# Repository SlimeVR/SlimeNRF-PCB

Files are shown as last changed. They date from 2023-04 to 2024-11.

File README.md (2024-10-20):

## notes

You need a segger jlink programmer to use this, USB dfu does not come with the initial bootloader of isp, and nrf52832 has no USB connectivity. nRF52840-dk development kit can be used, and also can double as a dongle for the trackers.

# slimenrf r3

Revision 3

E73-2G4M08S1C (nrf52840), icm42688 or compatible, mmc5983ma

https://oshwlab.com/sctanf/slimenrf3

# slimenrfaux2

Revision 2

isp1507-ax (nrf52832), icm42688 or compatible, mmc5983ma

* Uses nrf52832, no USB, SWD pins on dock connector instead
* No 0201 parts
* Removed onboard charger
* LED is brighter (sink instead of source)

pcb|3d
--|--
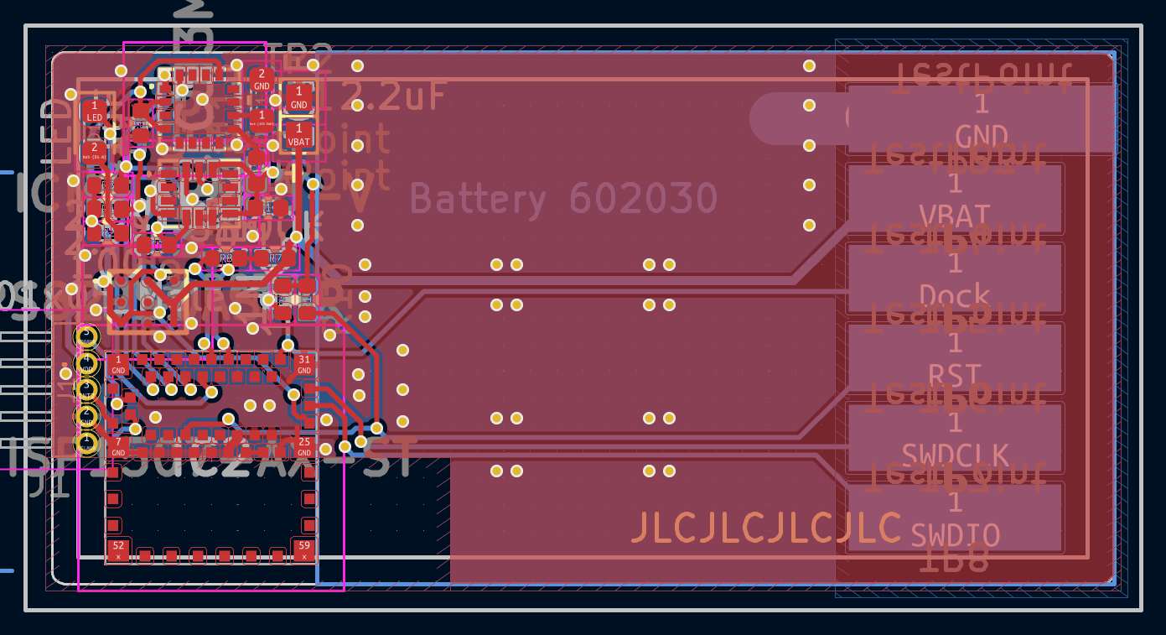
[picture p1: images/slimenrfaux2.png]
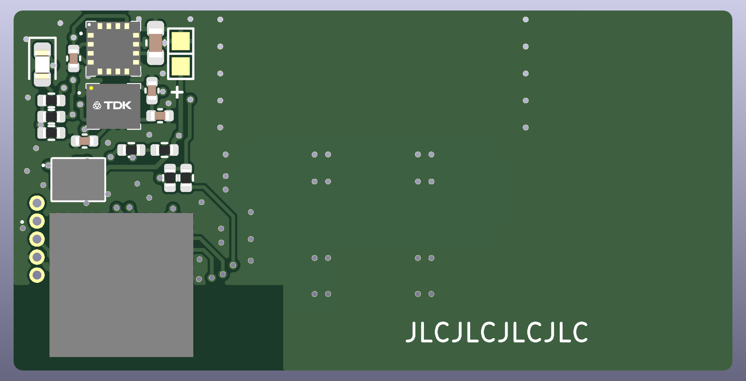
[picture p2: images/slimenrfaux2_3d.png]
|

pcb before reflow|pcb with battery|tracker and case (slimenrf_2.stl)
--|--|--
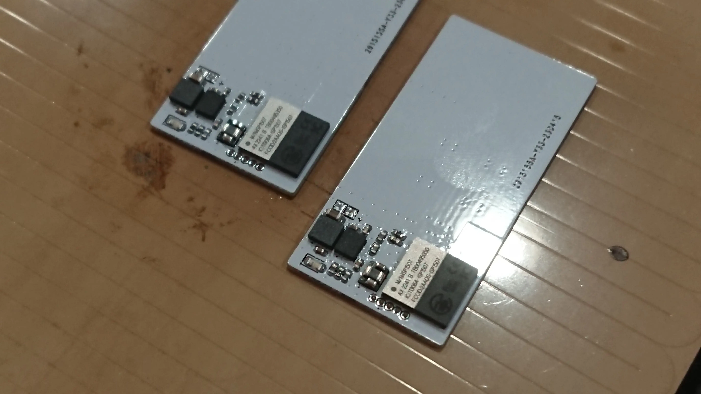
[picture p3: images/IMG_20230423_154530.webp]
pcb before reflow
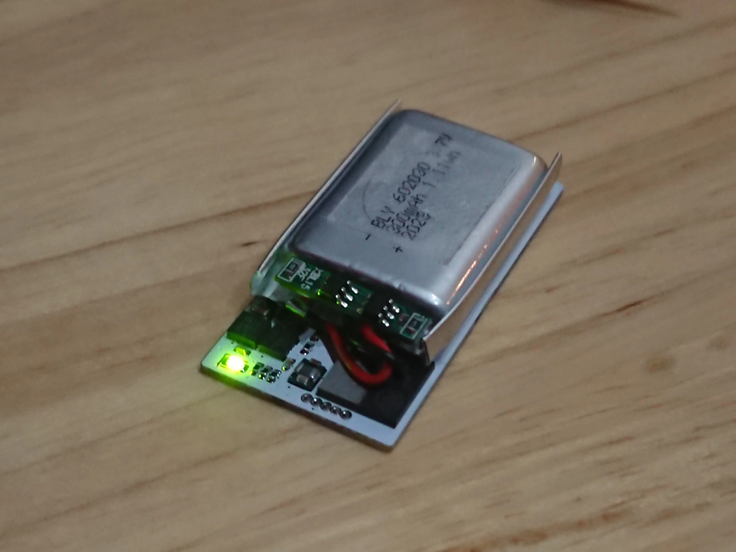
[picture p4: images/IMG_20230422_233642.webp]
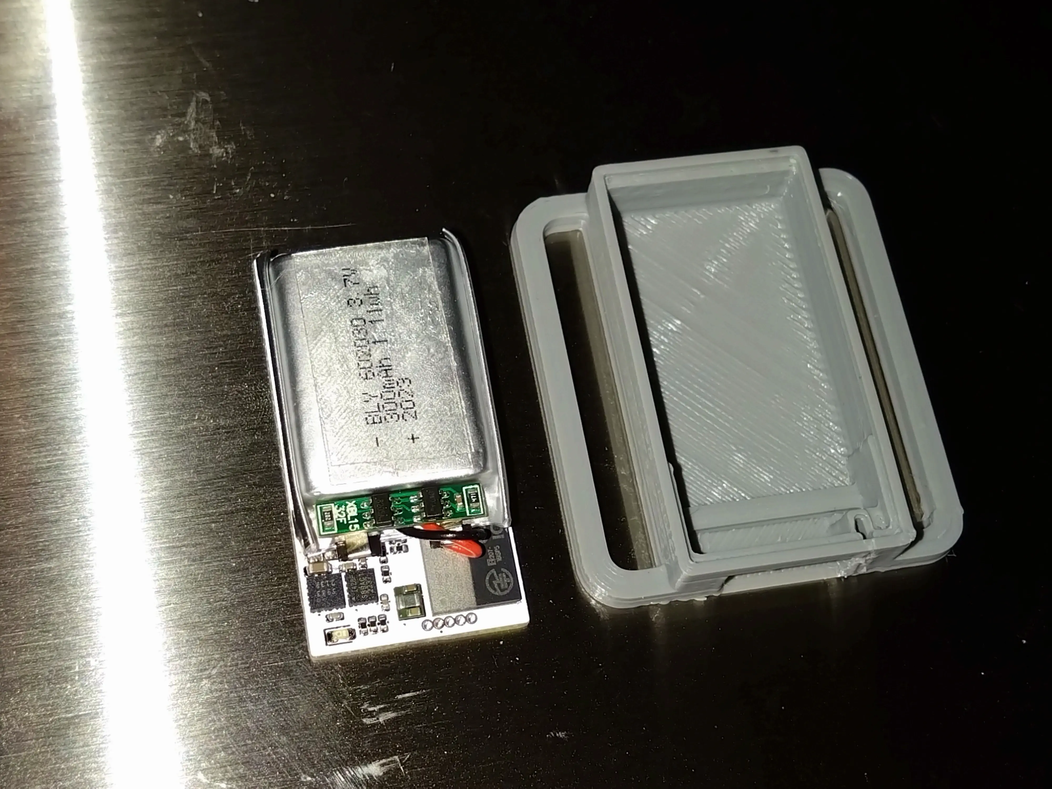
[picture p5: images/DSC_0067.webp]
tracker and case
||

# slimenrfauxaux2

Revision 2

icm42688 or compatible, mmc5983ma

pcb|3d
--|--
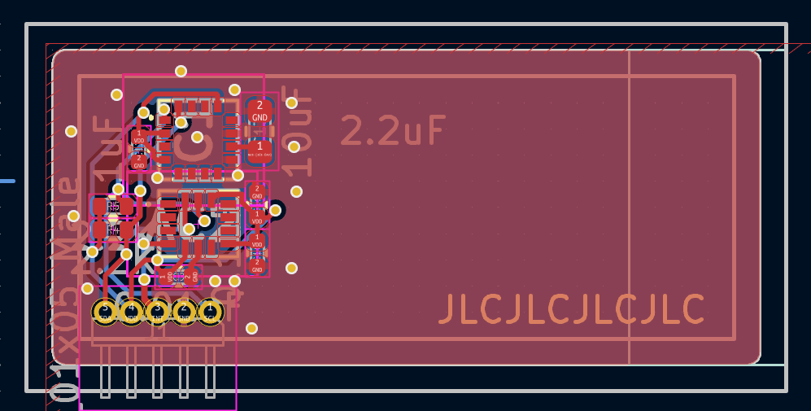
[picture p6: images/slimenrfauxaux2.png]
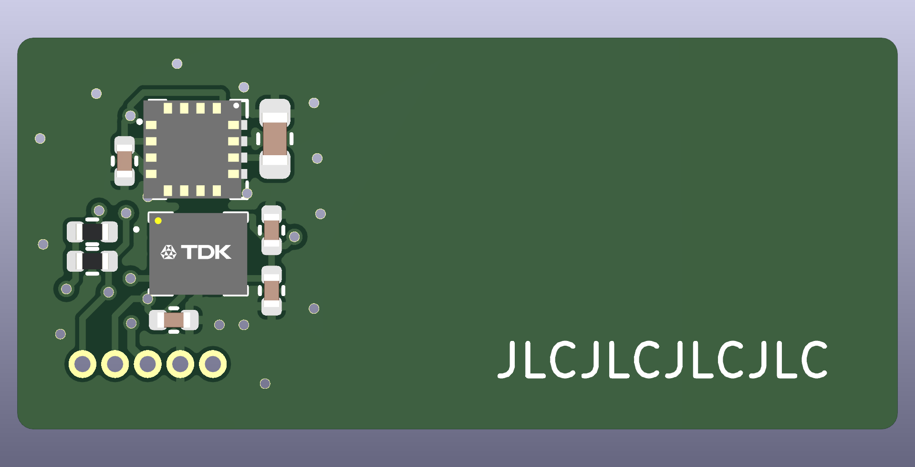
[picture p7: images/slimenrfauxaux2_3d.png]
|

# slimenrfaux

Revision 1

isp1807-lr (nrf52840), icm42688 or compatible, mmc5983ma

* USB untested
* 0201 components are hard to solder
* Charger is hard to solder
* LED with default resistor is too dim

pcb|3d
--|--
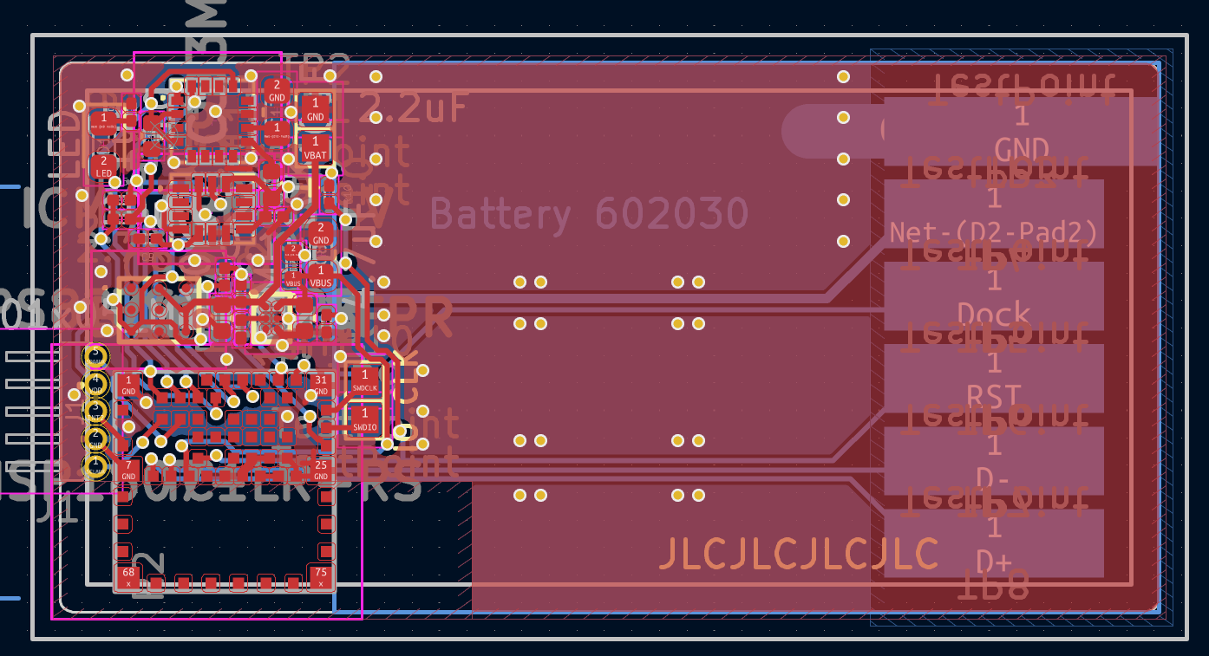
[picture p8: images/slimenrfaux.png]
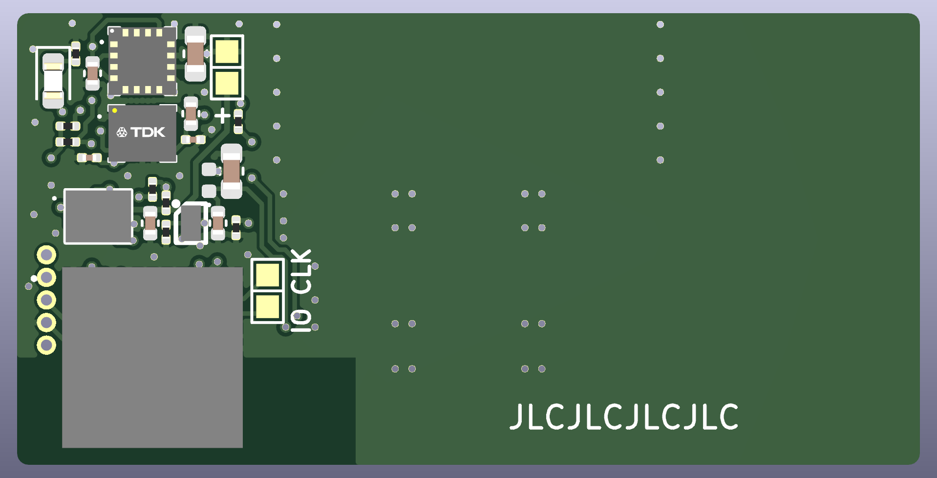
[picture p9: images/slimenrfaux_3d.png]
|

finished pcb|pcb with battery|completed tracker (case: slimenrf_2_closed.stl)
--|--|--
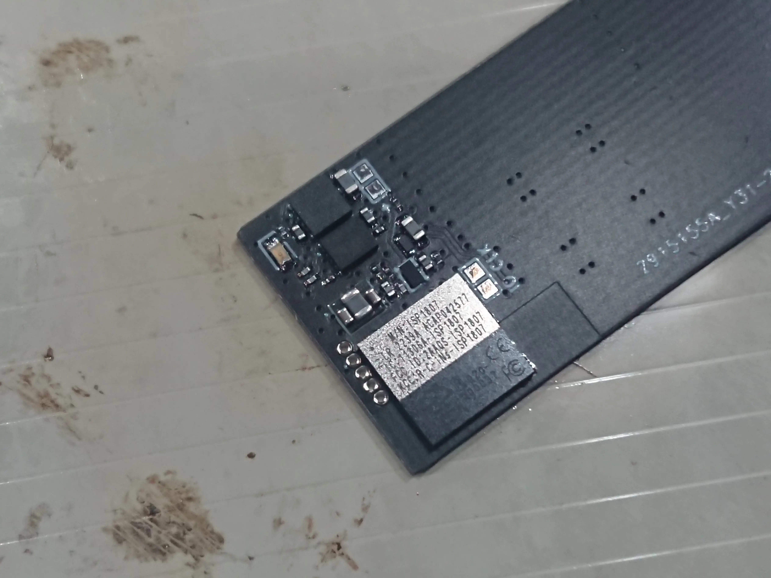
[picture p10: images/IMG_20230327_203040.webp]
finished pcb
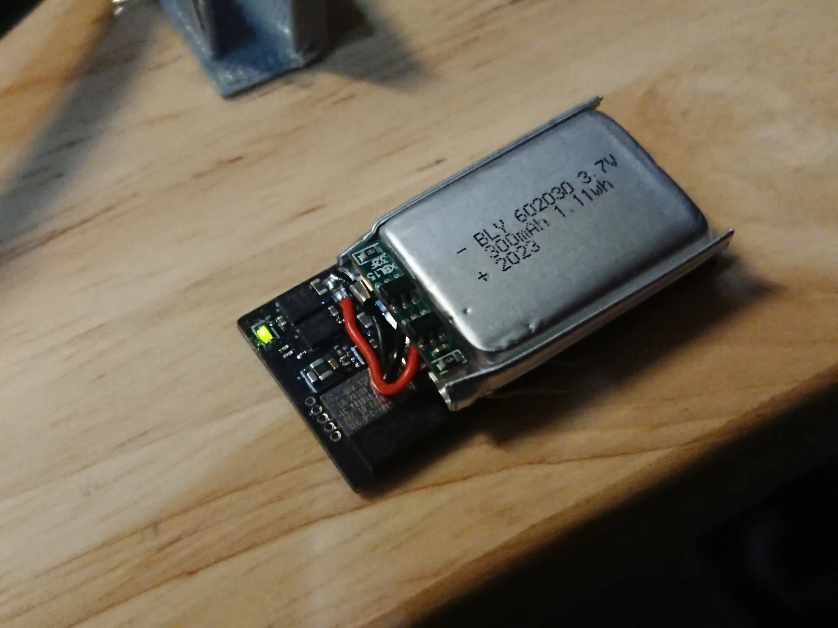
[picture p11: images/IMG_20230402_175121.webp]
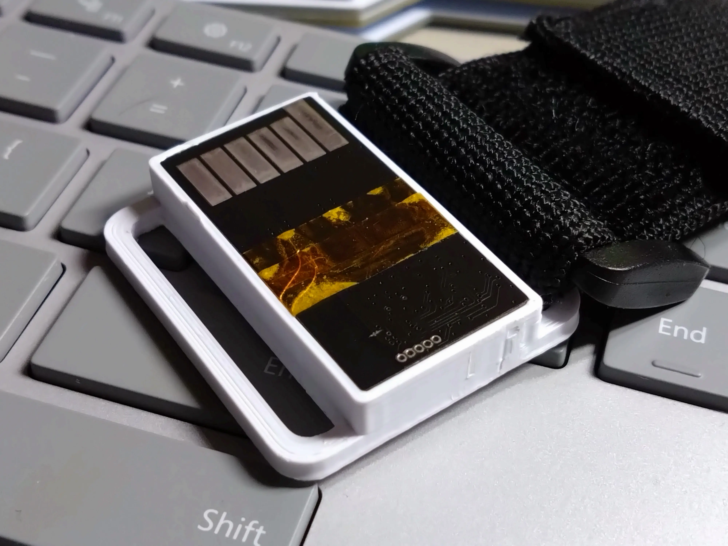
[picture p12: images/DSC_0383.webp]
completed tracker
||

# slimenrfauxaux

Revision 1

icm42688 or compatible, mmc5983ma

* 0201 components are hard to solder

pcb|3d
--|--
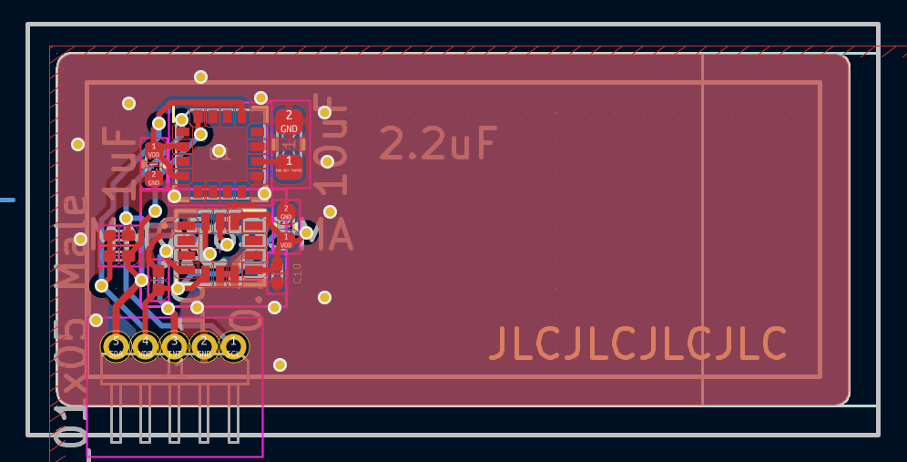
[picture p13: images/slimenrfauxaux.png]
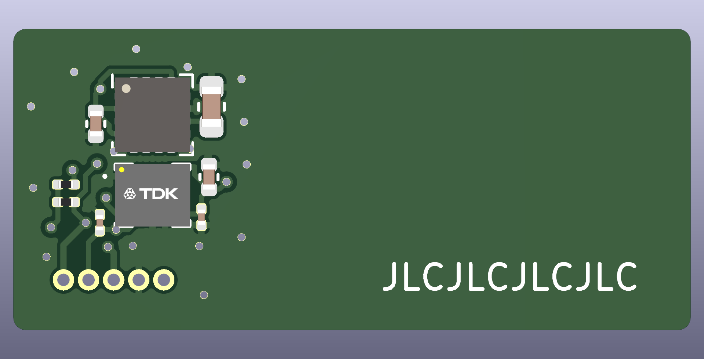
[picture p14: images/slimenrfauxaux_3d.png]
|

# slimenrfdock

dock test pcb

charging for 8 devices at 300mA, max power draw 2.4A

* Gets pretty hot if all 8 chargers are in use but it works fine

pcb|3d
--|--
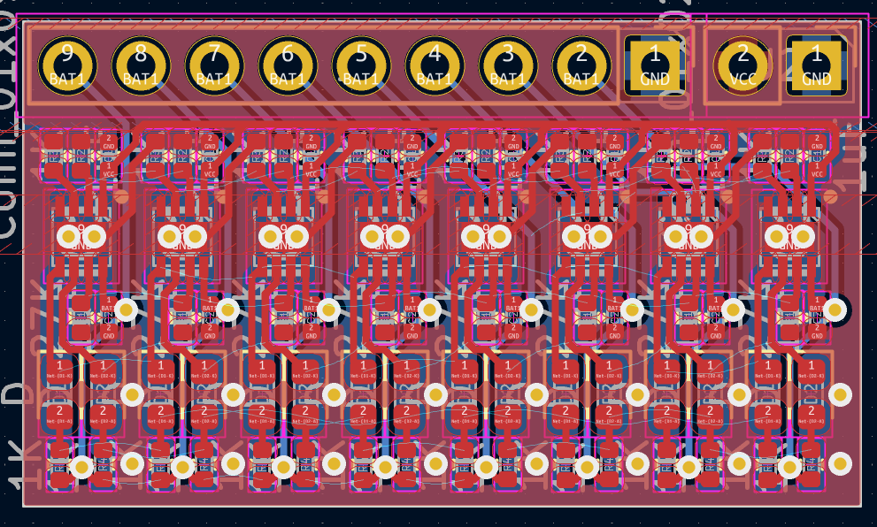
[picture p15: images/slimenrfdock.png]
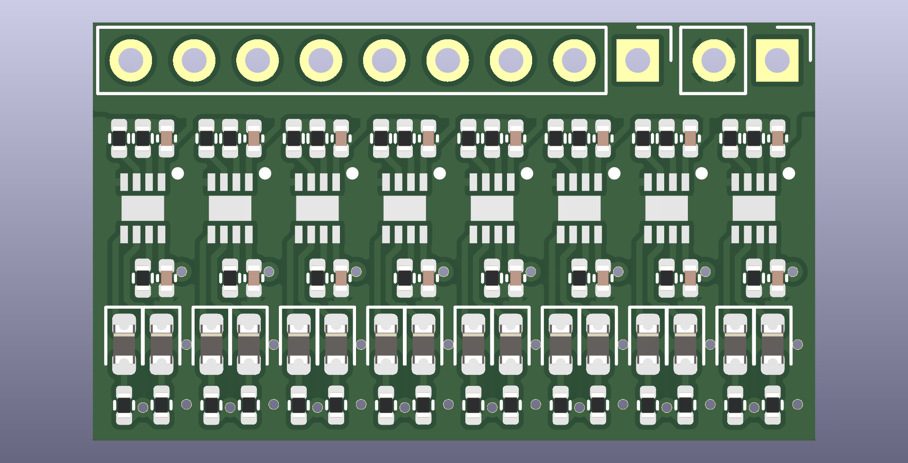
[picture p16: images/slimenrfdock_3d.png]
|

completed charger pcb|charging dock (slimenrfdock_2_6x_3pin.stl)
--|--
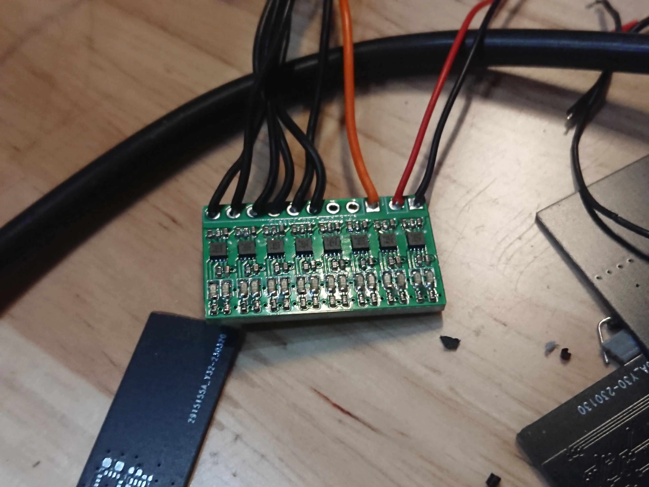
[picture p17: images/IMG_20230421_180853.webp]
completed charger pcb
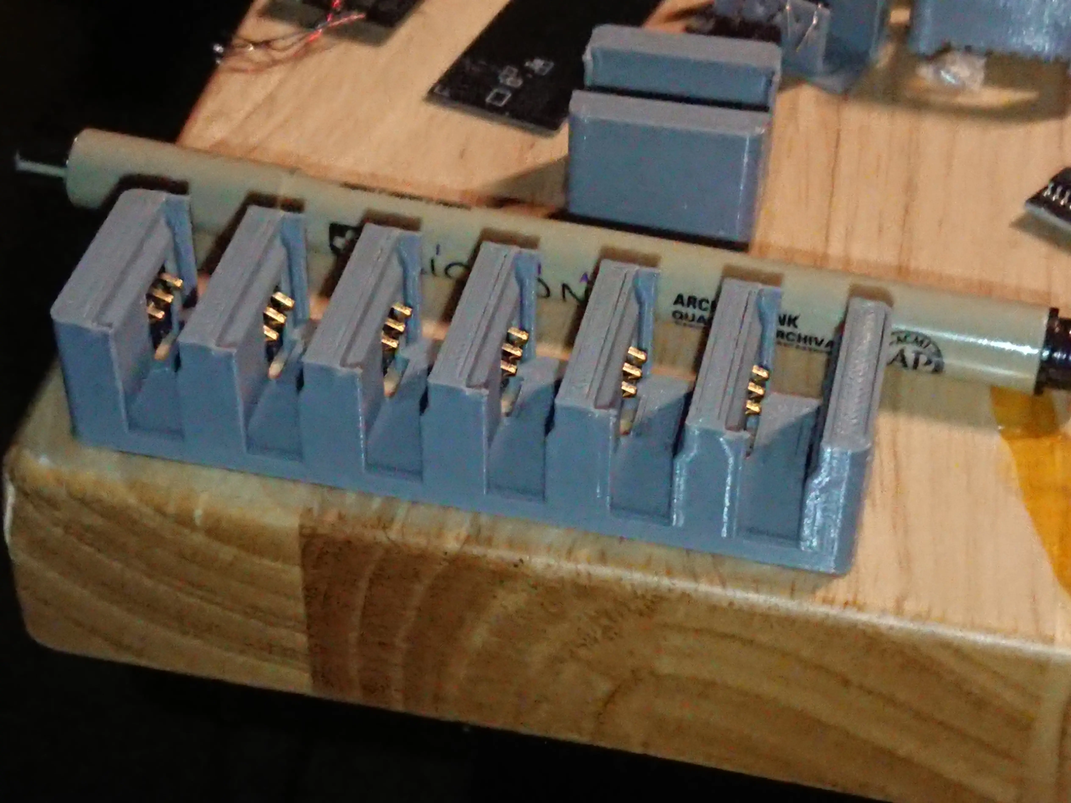
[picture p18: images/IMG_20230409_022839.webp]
charging dock
|

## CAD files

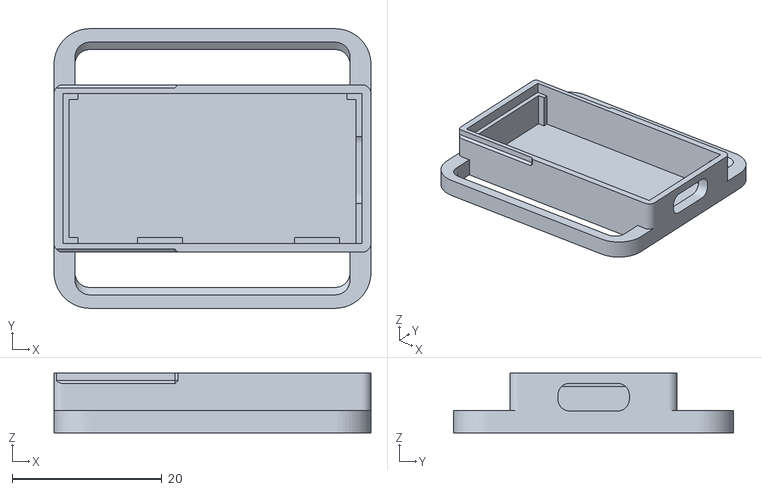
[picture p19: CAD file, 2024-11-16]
slimecase/slimenrf_6_r3.stl
42.4 x 37.4 x 8.00

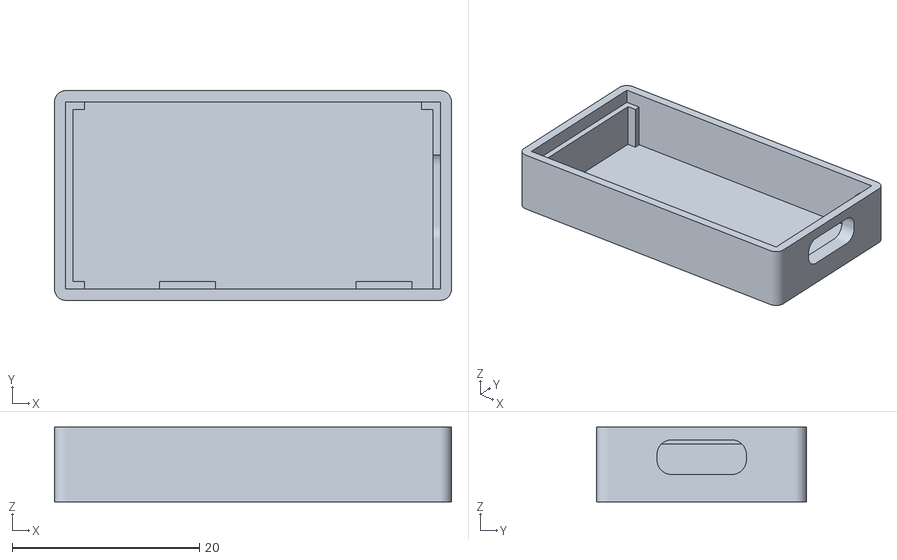
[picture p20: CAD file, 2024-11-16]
slimecase/slimenrf_6_usb.stl
42.4 x 22.4 x 8.00

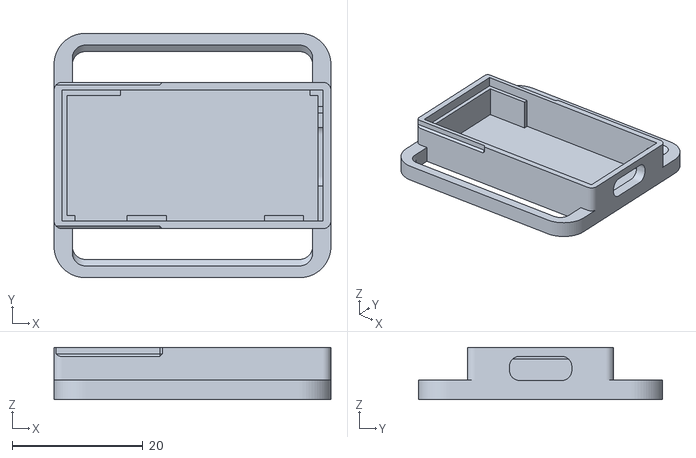
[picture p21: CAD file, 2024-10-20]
slimecase/slimenrf_6_r3_ledcutout.stl
42.4 x 37.4 x 8.00

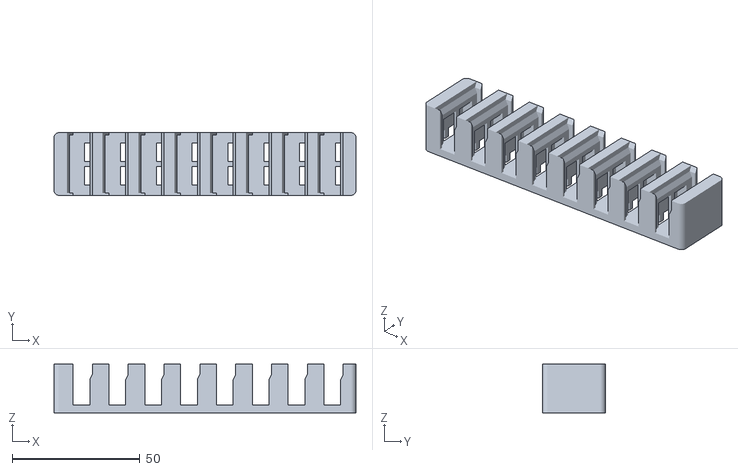
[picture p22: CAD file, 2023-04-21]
slimecase/slimenrfdock_2_8x.stl
118.0 x 24.5 x 19.0

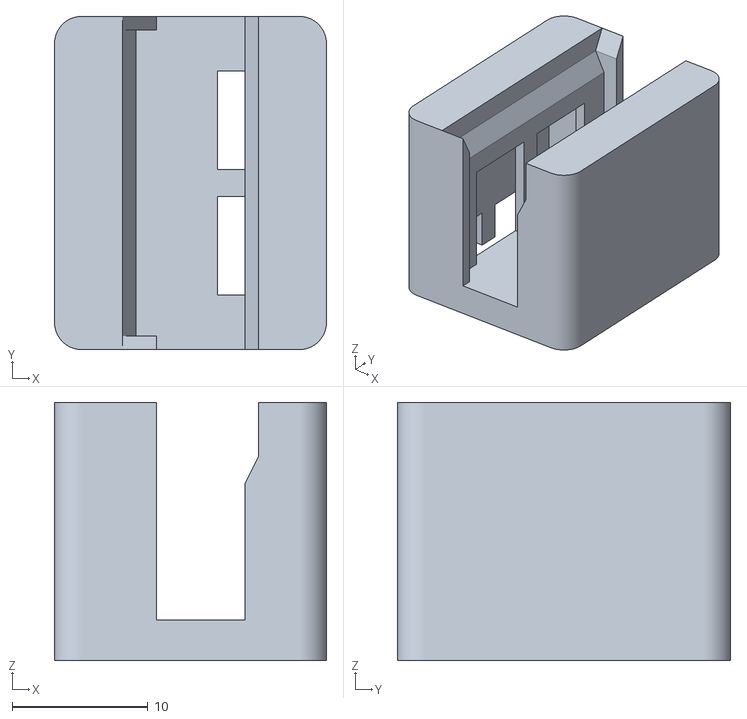
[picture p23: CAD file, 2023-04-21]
slimecase/slimenrfdock_2_1x.stl
20.0 x 24.5 x 19.0

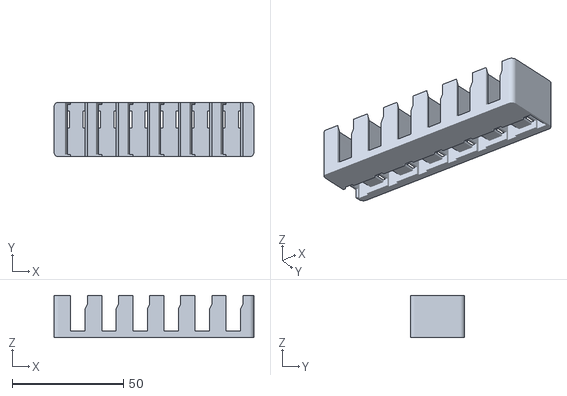
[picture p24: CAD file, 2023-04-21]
slimecase/slimenrfdock_2_6x_3pin.stl
90.0 x 24.5 x 19.0

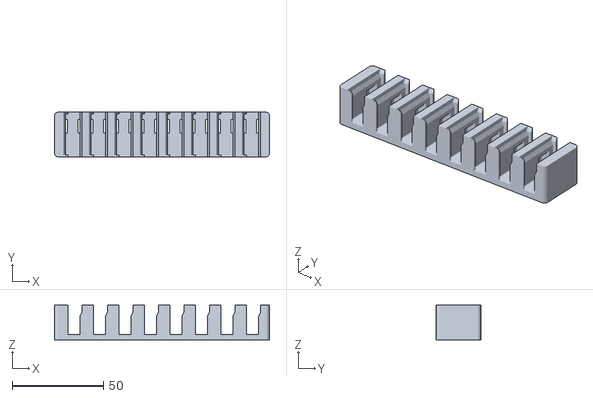
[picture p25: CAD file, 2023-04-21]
slimecase/slimenrfdock_2_8x_3pin.stl
118.0 x 24.5 x 19.0

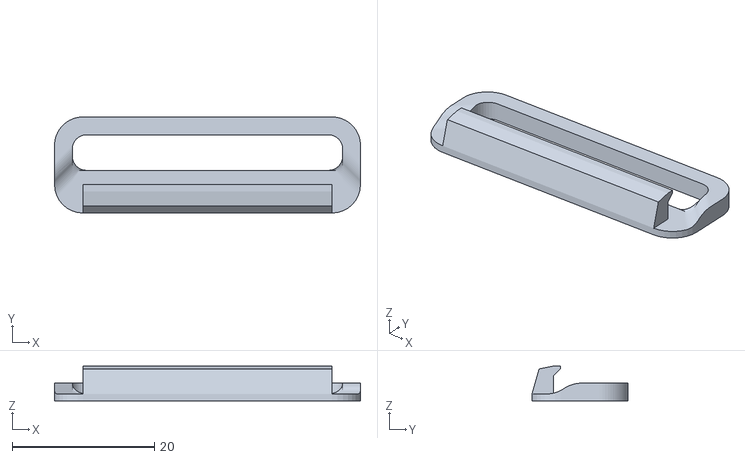
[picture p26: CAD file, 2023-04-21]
slimecase/slimenrf_38mmstrapclip.stl
43.0 x 13.5 x 4.90

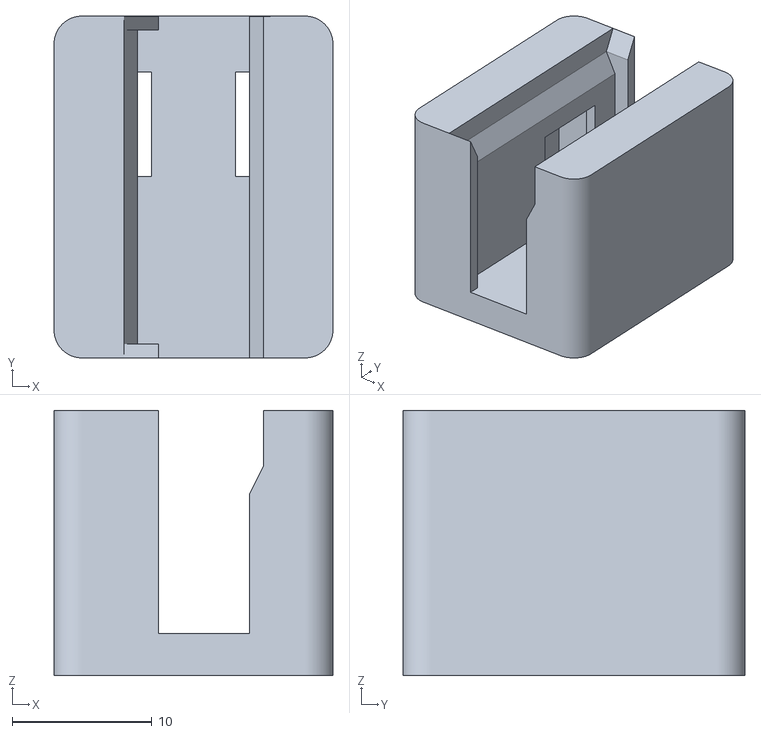
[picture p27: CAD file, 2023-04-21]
slimecase/slimenrfdock_2_1x_3pin.stl
20.0 x 24.5 x 19.0

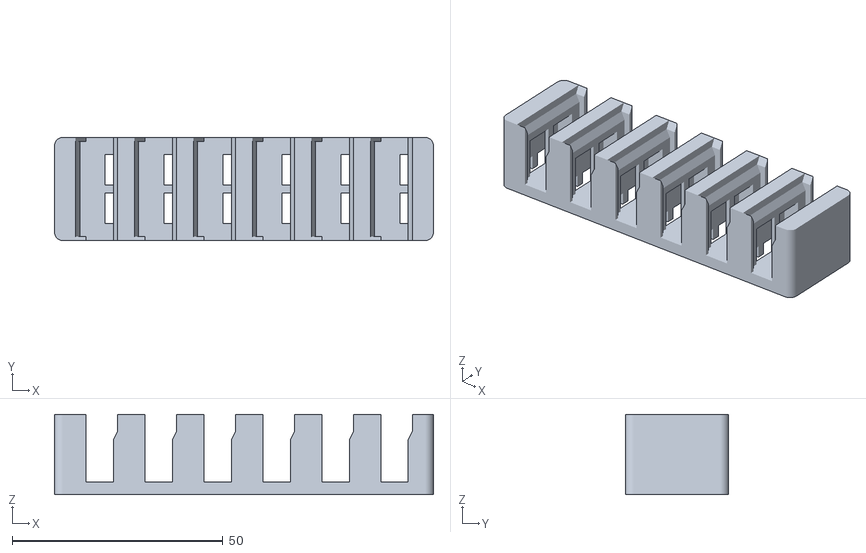
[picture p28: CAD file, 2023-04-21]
slimecase/slimenrfdock_2_6x.stl
90.0 x 24.5 x 19.0

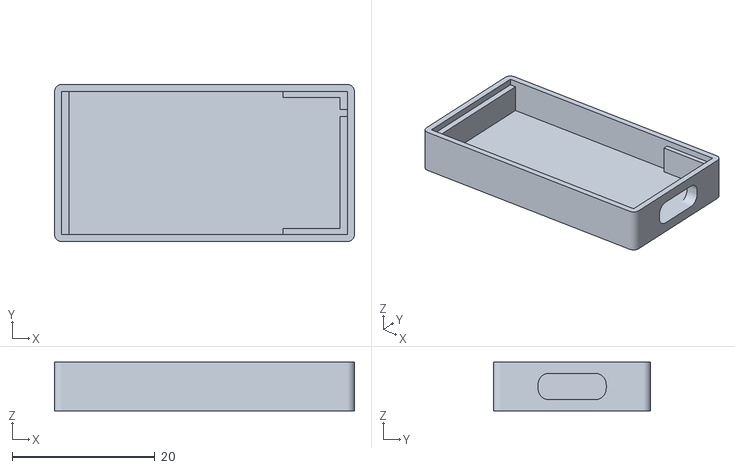
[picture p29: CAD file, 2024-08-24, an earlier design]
slimecase/old/slimenrf_3_supermini_receiver.stl
42.0 x 22.0 x 6.84

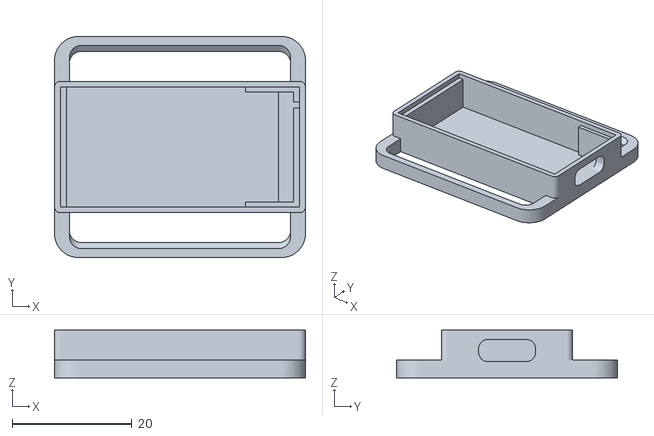
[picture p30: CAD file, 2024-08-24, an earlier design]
slimecase/old/slimenrf_3_supermini.stl
42.0 x 37.0 x 8.00

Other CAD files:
slimecase/slimenrf_6_r3_button.stl
slimecase/slimenrf_6_r3_button_ledcutout.stl
slimecase/slimenrf_6_r2_ledcutout.stl
slimecase/slimenrf_6_r2.stl
slimecase/old/slimenrf_3_closed.stl
slimecase/old/slimenrf_3_r3.stl
slimecase/old/slimenrf_2.blend
slimecase/old/slimenrf_2.stl
slimecase/old/slimenrf_2_closed.stl
slimecase/old/slimenrf_3_closed.blend
slimecase/old/slimenrf_3_r3.blend
slimecase/old/slimenrf_3_supermini.blend
slimecase/old/slimenrf_3_supermini_receiver.blend
slimecase/old/slimenrfaux_2_thick.blend
slimecase/old/slimenrfaux_2_thick_38mm.blend
slimecase/old/slimenrfaux_2_thick_38mm.stl
slimecase/old/slimenrfaux_2_thin.blend
slimecase/old/slimenrfaux_2_thin_38mm.blend
slimecase/slimenrfdock_2_ends.blend
slimecase/slimenrfdock_2_ends_3pin.blend
slimecase/slimenrfdock_2_ends_3pin_2.blend
slimecase/slimenrfdock_2_main.blend
slimecase/slimenrfdock_2_main_3pin.blend

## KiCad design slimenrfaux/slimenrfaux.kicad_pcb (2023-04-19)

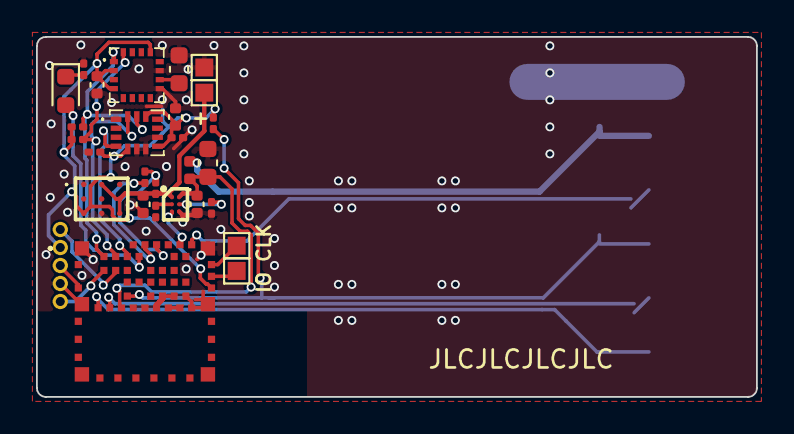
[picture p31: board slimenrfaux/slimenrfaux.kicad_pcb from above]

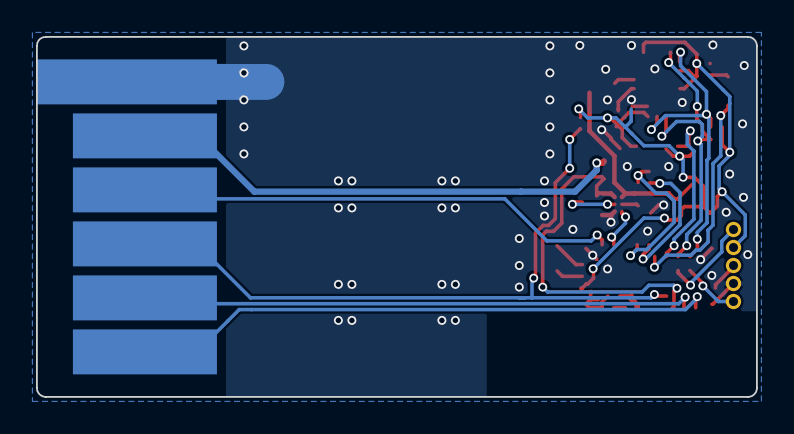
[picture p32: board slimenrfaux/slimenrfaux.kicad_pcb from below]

Board: 2 copper layers, 40.0 x 20.0 mm, 34 parts (6 on the bottom side), 26 nets.

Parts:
AC2: ICM-42688-V; IIM42352
C3, C4, C12: 1uF; C_0402_1005Metric
C8: 4.7uF; C_0603_1608Metric
C9: 10nF; C_0201_0603Metric
C10: 0.1uF; C_0201_0603Metric
C11: 2.2uF; C_0402_1005Metric
C13: 10uF; C_0603_1608Metric
D1: LED; LED_0603_1608Metric
D2: D; D_0402_1005Metric
IC1: ISP1807-LR-RS; ISP1807LRRS
IC2: BQ25101YFPR; BGA6C40P2X3_88X158X50
IC3: MMC5983MA
J1: Conn_01x05_Male; PinHeader_1x05_P1.00mm_Horizontal
PS1: TPS82740ASIPR
R1, R10: 10K; R_0201_0603Metric
R2: 540; R_0201_0603Metric
R4, R5: 2.7K; R_0201_0603Metric
R7: 1M; R_0201_0603Metric
R8: 510K; R_0201_0603Metric
R9: 10; R_0201_0603Metric
TP1, TP2, TP3, TP4, TP5, TP6, TP7, TP8, TP9, TP10: TestPoint; TestPoint_Pad_1.0x1.0mm

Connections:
ADCBAT: IC1.38 (P0_03_AIN1), R7.2, R8.1
ADCBATEN: IC1.40 (P0_02_AIN0), R8.2
CHGSTAT: IC1.34 (P0_06), IC2.C1 (~CHG)
D+: IC1.8 (D+), TP8.1
D-: IC1.10 (D-), TP7.1
Dock: IC1.32 (P0_08), TP5.1
GND: AC2.1 (AP_SDO_/_AP_AD0), AC2.6 (GND), AC2.7 (RESV_3), AC2.9 (INT2_/_FSYNC_/_CLKIN), C3.1, C4.2, C8.2, C9.2, C10.2, C11.2, C12.2, C13.2, IC1.1 (VSS_1), IC1.7 (VSS_2), IC1.14 (VSS_3), IC1.16 (VSS_4), IC1.18 (VSS_5), IC1.19 (P0_24), IC1.21 (VSS_6), IC1.23 (VSS_7), IC1.24 (VSS_8), IC1.25 (VSS_9), IC1.31 (VSS_10), IC2.C2 (VSS), IC3.9 (GND_1), IC3.11 (GND_2), J1.2, PS1.A1 (VSEL3), PS1.A3 (VSEL1), PS1.C2 (GND), R1.1, R2.2, R9.2, TP2.1, TP3.1
INT: AC2.4 (INT1_/_INT), IC1.43 (P0_11_TRACEDATA2)
INT2: IC1.6 (P0_26), J1.3
LED: D1.2 (A), IC1.41 (P0_25)
unnamed: C13.1, IC3.10 (CAP)
unnamed: D2.2 (A), TP4.1
unnamed: IC1.20 (OUT_ANT), IC1.22 (OUT_MOD)
unnamed: IC2.B1 (TS), R1.2
unnamed: IC2.B2 (ISET), R2.1
unnamed: D1.1 (K), R9.1
RST: IC1.13 (P0_18_RESET), R10.2, TP6.1
SCL: AC2.13 (AP_SCL_/_AP_SCLK), IC1.47 (P0_23), IC3.1 (SCL/SPI_SCK), R5.2
SCLAUX: IC1.56 (P1_09_TRACEDATA3), J1.1
SDA: AC2.14 (AP_SDA_/_AP_SDIO_/_AP_SDI), IC1.45 (P0_19), IC3.16 (SDA/SPI_SDI), R4.2
SDAAUX: IC1.55 (P1_08), J1.5
SWDCLK: IC1.30 (SWDCLK), TP10.1
SWDIO: IC1.28 (SWDIO), TP9.1
VBAT: C3.2, IC2.A1 (OUT), PS1.A2 (VSEL2), PS1.B3 (EN), PS1.C3 (VIN), R7.1, TP1.1
VBUS: C4.1, C8.1, D2.1 (K), IC1.12 (VBUS), IC2.A2 (IN)
VDD: AC2.5 (VDDIO), AC2.8 (VDD), AC2.12 (AP_CS), C9.1, C10.1, C11.1, C12.1, IC1.26 (VCC_NRF), IC3.2 (VDD), IC3.4 (SPI_CS), IC3.13 (VDDIO), J1.4, PS1.C1 (VOUT), R4.1, R5.1, R10.1

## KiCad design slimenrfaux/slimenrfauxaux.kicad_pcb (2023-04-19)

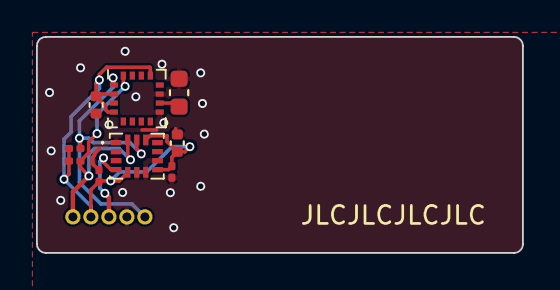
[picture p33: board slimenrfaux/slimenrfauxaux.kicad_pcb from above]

Board: 2 copper layers, 27.0 x 12.0 mm, 10 parts (0 on the bottom side), 6 nets.

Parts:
AC2: ICM-42688-V; IIM42352
C9: 10nF; C_0201_0603Metric
C10: 0.1uF; C_0201_0603Metric
C11: 2.2uF; C_0402_1005Metric
C12: 1uF; C_0402_1005Metric
C13: 10uF; C_0603_1608Metric
J1: Conn_01x05_Male; PinHeader_1x05_P1.00mm_Horizontal
R4, R5: 2.2K; R_0201_0603Metric
U1: MMC5883MA; LGA-16_3x3mm_P0.5mm

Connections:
GND: AC2.1 (AP_SDO_/_AP_AD0), AC2.6 (GND), AC2.7 (RESV_3), AC2.9 (INT2_/_FSYNC_/_CLKIN), C9.2, C10.2, C11.2, C12.2, C13.2, J1.2, U1.9 (GND), U1.11 (GND)
INT: AC2.4 (INT1_/_INT), J1.3
unnamed: C13.1, U1.10 (CAP)
SCL: AC2.13 (AP_SCL_/_AP_SCLK), J1.1, R5.2, U1.1 (SCL)
SDA: AC2.14 (AP_SDA_/_AP_SDIO_/_AP_SDI), J1.5, R4.2, U1.16 (SDA)
VDD: AC2.5 (VDDIO), AC2.8 (VDD), AC2.12 (AP_CS), C9.1, C10.1, C11.1, C12.1, J1.4, R4.1, R5.1, U1.2 (VDD), U1.4 (NC), U1.13 (VDDIO)

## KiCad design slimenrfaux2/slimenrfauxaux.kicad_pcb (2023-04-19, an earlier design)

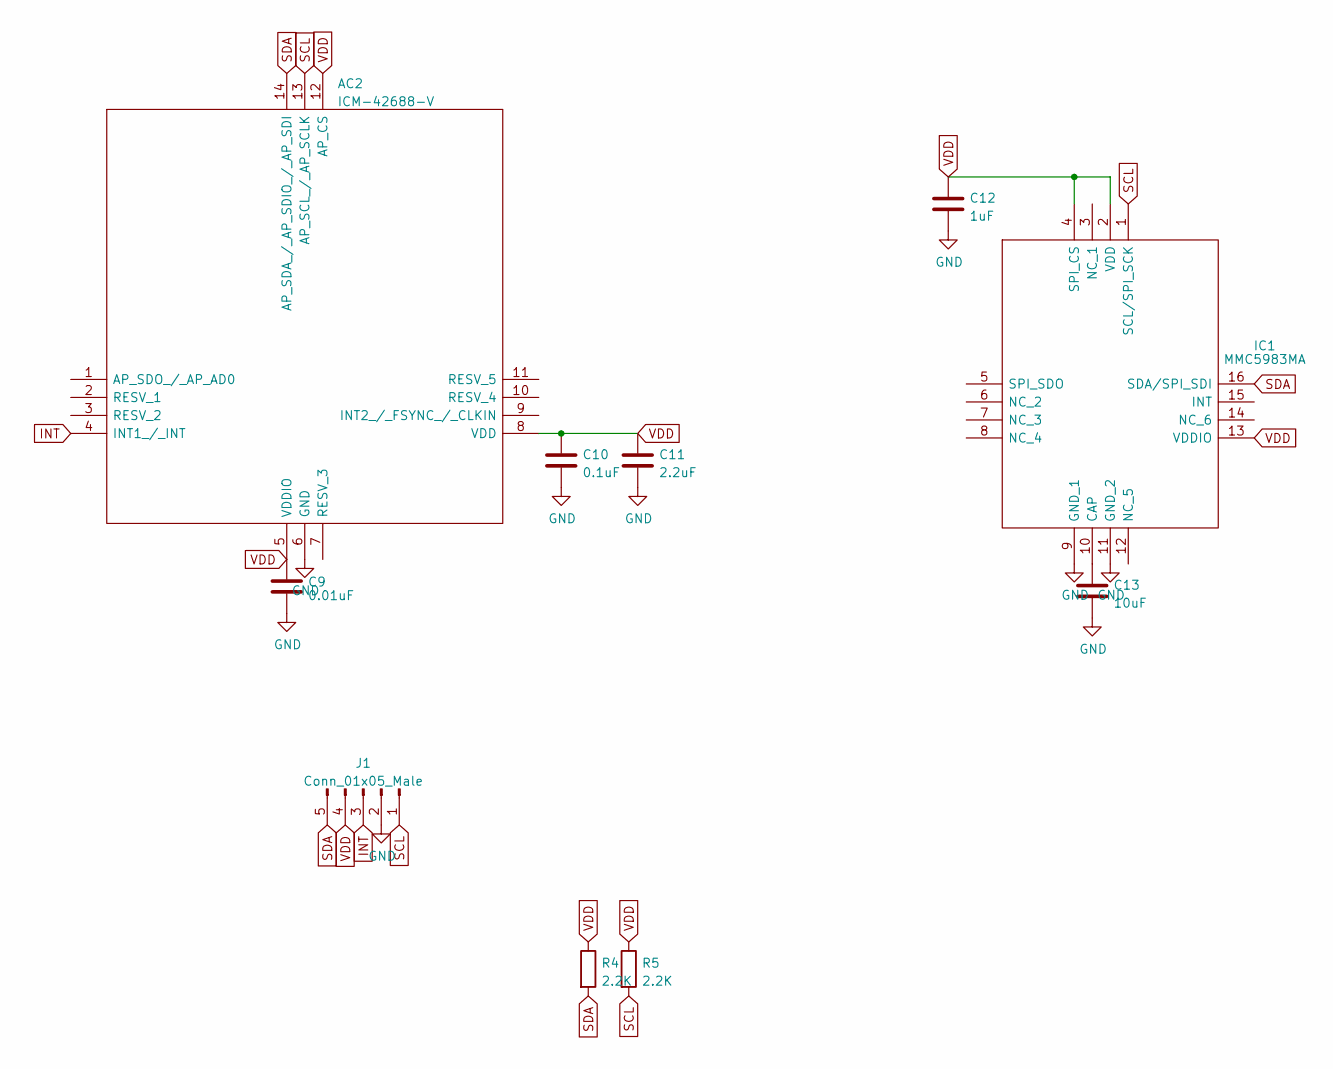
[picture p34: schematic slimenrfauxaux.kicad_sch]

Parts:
AC2: ICM-42688-V; IIM42352; Mouser Part Number 410-ICM-42688-V
C9: 0.01uF; C_0402_1005Metric
C10: 0.1uF; C_0402_1005Metric
C11: 2.2uF; C_0402_1005Metric
C12: 1uF; C_0402_1005Metric
C13: 10uF; C_0603_1608Metric
IC1: MMC5983MA; Mouser Part Number 438-MMC5983MA
J1: Conn_01x05_Male; PinHeader_1x05_P1.00mm_Horizontal
R4, R5: 2.2K; R_0402_1005Metric

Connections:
GND: AC2.6 (GND), C9.2, C10.2, C11.2, C12.2, C13.2, IC1.9 (GND_1), IC1.11 (GND_2), J1.2
INT: AC2.4 (INT1_/_INT), J1.3
unnamed: C13.1, IC1.10 (CAP)
SCL: AC2.13 (AP_SCL_/_AP_SCLK), IC1.1 (SCL/SPI_SCK), J1.1, R5.2
SDA: AC2.14 (AP_SDA_/_AP_SDIO_/_AP_SDI), IC1.16 (SDA/SPI_SDI), J1.5, R4.2
VDD: AC2.5 (VDDIO), AC2.8 (VDD), AC2.12 (AP_CS), C9.1, C10.1, C11.1, C12.1, IC1.2 (VDD), IC1.4 (SPI_CS), IC1.13 (VDDIO), J1.4, R4.1, R5.1

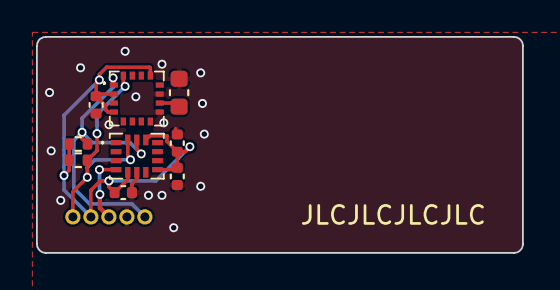
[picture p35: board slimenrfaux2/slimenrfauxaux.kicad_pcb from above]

Board: 2 copper layers, 27.0 x 12.0 mm, 10 parts (0 on the bottom side), 6 nets.

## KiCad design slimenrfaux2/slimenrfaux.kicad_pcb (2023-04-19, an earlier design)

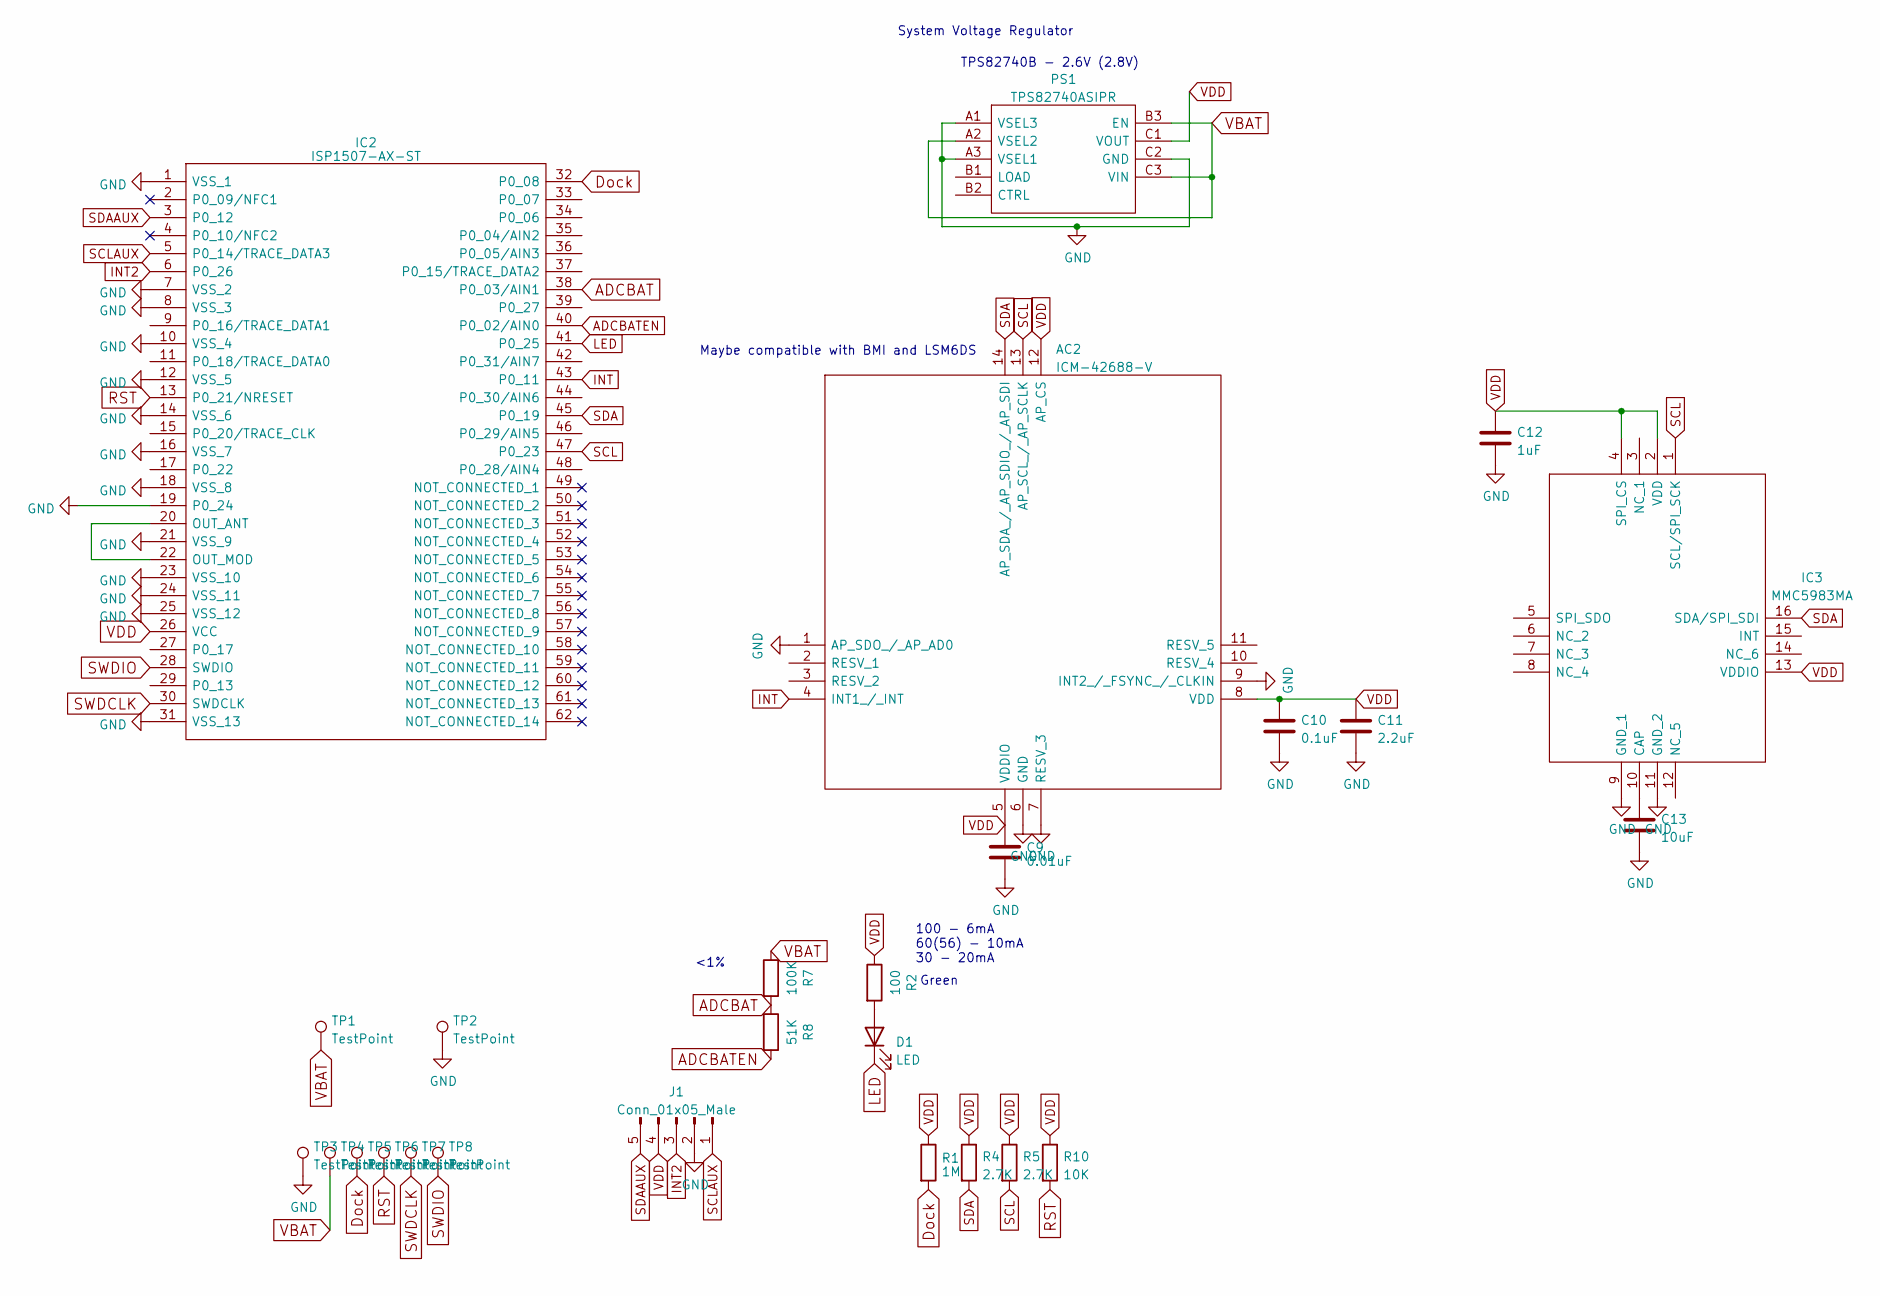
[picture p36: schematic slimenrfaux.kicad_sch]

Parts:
AC2: ICM-42688-V; IIM42352; Mouser Part Number 410-ICM-42688-V
C9: 0.01uF; C_0402_1005Metric
C10: 0.1uF; C_0402_1005Metric
C11: 2.2uF; C_0402_1005Metric
C12: 1uF; C_0402_1005Metric
C13: 10uF; C_0603_1608Metric
D1: LED; LED_0603_1608Metric
IC2: ISP1507-AX-ST; ISP1507AXST; Manufacturer_Part_Number ISP1507-AX-ST; Mouser Part Number 359-ISP1507-AX-ST
IC3: MMC5983MA; Mouser Part Number 438-MMC5983MA
J1: Conn_01x05_Male; PinHeader_1x05_P1.00mm_Horizontal
PS1: TPS82740ASIPR; Mouser Part Number 595-TPS82740ASIPR
R1: 1M; R_0402_1005Metric
R2: 100; R_0402_1005Metric
R4, R5: 2.7K; R_0402_1005Metric
R7: 100K; R_0402_1005Metric
R8: 51K; R_0402_1005Metric
R10: 10K; R_0402_1005Metric
TP1, TP2, TP3, TP4, TP5, TP6, TP7, TP8: TestPoint; TestPoint_Pad_1.0x1.0mm

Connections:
ADCBAT: IC2.38 (P0_03/AIN1), R7.2, R8.1
ADCBATEN: IC2.40 (P0_02/AIN0), R8.2
Dock: IC2.32 (P0_08), R1.2, TP5.1
GND: AC2.1 (AP_SDO_/_AP_AD0), AC2.6 (GND), AC2.7 (RESV_3), AC2.9 (INT2_/_FSYNC_/_CLKIN), C9.2, C10.2, C11.2, C12.2, C13.2, IC2.1 (VSS_1), IC2.7 (VSS_2), IC2.8 (VSS_3), IC2.10 (VSS_4), IC2.12 (VSS_5), IC2.14 (VSS_6), IC2.16 (VSS_7), IC2.18 (VSS_8), IC2.19 (P0_24), IC2.21 (VSS_9), IC2.23 (VSS_10), IC2.24 (VSS_11), IC2.25 (VSS_12), IC2.31 (VSS_13), IC3.9 (GND_1), IC3.11 (GND_2), J1.2, PS1.A1 (VSEL3), PS1.A3 (VSEL1), PS1.C2 (GND), TP2.1, TP3.1
INT: AC2.4 (INT1_/_INT), IC2.43 (P0_11)
INT2: IC2.6 (P0_26), J1.3
LED: D1.1 (K), IC2.41 (P0_25)
unnamed: D1.2 (A), R2.2
unnamed: IC2.20 (OUT_ANT), IC2.22 (OUT_MOD)
unnamed: C13.1, IC3.10 (CAP)
RST: IC2.13 (P0_21/NRESET), R10.2, TP6.1
SCL: AC2.13 (AP_SCL_/_AP_SCLK), IC2.47 (P0_23), IC3.1 (SCL/SPI_SCK), R5.2
SCLAUX: IC2.5 (P0_14/TRACE_DATA3), J1.1
SDA: AC2.14 (AP_SDA_/_AP_SDIO_/_AP_SDI), IC2.45 (P0_19), IC3.16 (SDA/SPI_SDI), R4.2
SDAAUX: IC2.3 (P0_12), J1.5
SWDCLK: IC2.30 (SWDCLK), TP7.1
SWDIO: IC2.28 (SWDIO), TP8.1
VBAT: PS1.A2 (VSEL2), PS1.B3 (EN), PS1.C3 (VIN), R7.1, TP1.1, TP4.1
VDD: AC2.5 (VDDIO), AC2.8 (VDD), AC2.12 (AP_CS), C9.1, C10.1, C11.1, C12.1, IC2.26 (VCC), IC3.2 (VDD), IC3.4 (SPI_CS), IC3.13 (VDDIO), J1.4, PS1.C1 (VOUT), R1.1, R2.1, R4.1, R5.1, R10.1

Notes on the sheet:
System Voltage Regulator
TPS82740B - 2.6V (2.8V)
Green
100 - 6mA 60(56) - 10mA 30 - 20mA
Maybe compatible with BMI and LSM6DS
<1%

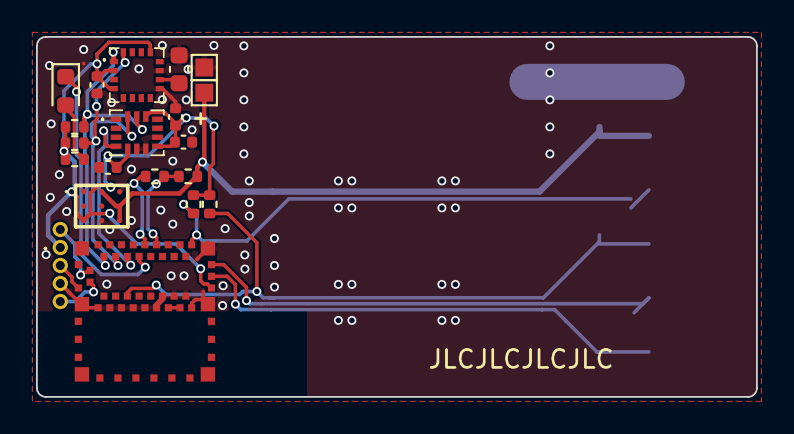
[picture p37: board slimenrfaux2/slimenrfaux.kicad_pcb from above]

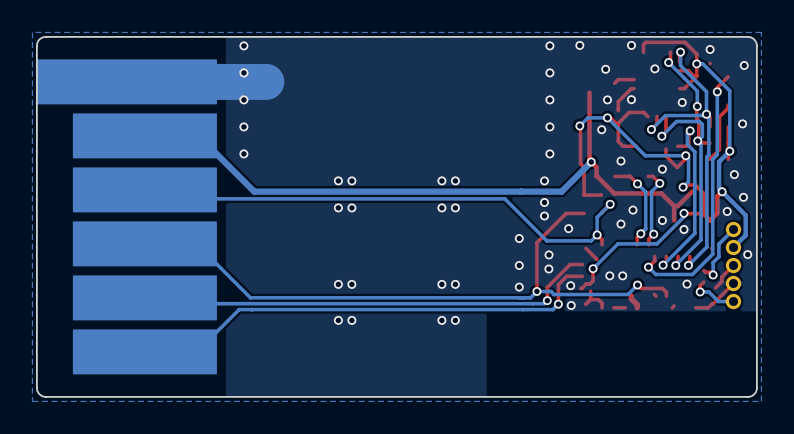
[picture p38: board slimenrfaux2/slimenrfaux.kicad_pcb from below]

Board: 2 copper layers, 40.0 x 20.0 mm, 26 parts (6 on the bottom side), 19 nets.

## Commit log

2023-04-19 add dock pcb
    [slimenrfdock.kicad_pcb, slimenrfdock.kicad_sch]
2023-04-19 add recent tracker pcbs
    [slimenrfaux.kicad_pcb, slimenrfaux.kicad_sch, slimenrfauxaux.kicad_pcb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]
2023-04-19 add older tracker pcbs
    [slimenrfaux.kicad_pcb, slimenrfaux.kicad_sch, slimenrfauxaux.kicad_pcb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]
2023-04-21 add model files
    [slimenrf_2.blend, slimenrf_2.stl, slimenrf_38mmstrapclip.stl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]
2024-01-04 add case with removed ext port
    [slimenrf_2_closed.stl]
2024-01-04 add pictures of finished boards
2024-08-24 add r3 board (link)
2024-10-20 add updated case model
    [slimenrf_2.blend, slimenrf_2.stl, slimenrf_2_closed.stl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]
2024-11-16 update case
    remove extended ledge which may dig into battery
    [slimenrf_6_r3.stl, slimenrf_6_r3_button.stl, slimenrf_6_usb.stl]
